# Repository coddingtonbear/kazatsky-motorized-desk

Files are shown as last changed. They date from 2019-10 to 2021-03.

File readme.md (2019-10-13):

header-image

# Kazatsky: DIY Motorized IKEA Desk

The project herein is everything I used for converting my manually-cranked [IKEA Skarsta Desk](https://www.ikea.com/us/en/p/skarsta-desk-sit-stand-white-s49084965/) into a motorized one using parts from a cheap [Harbor Freight 18v Drill Master Drill](https://www.harborfreight.com/18-Volt-38-in-Cordless-DrillDriver-Kit-With-Keyless-Chuck-21-Clutch-Settings-62873.html), a DIY Atmega328pb-based PCB, a [BTS7960 motor driver module](https://www.amazon.com/DEVMO-BTS7960B-Stepper-H-Bridge-Arduino/dp/B07SZ4T699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), a handful of 3D-printed parts, and miscellaneous hardware.

You can also find the 3d-printed parts on Thingiverse: https://www.thingiverse.com/thing:3912988

This is named after the traditional Russian folk dance called the "Kazatsky" because of the parallels that can be drawn between that dance's main movement and the comically fast speed at which this desk can be raised up and down when running the drill at full-bore.

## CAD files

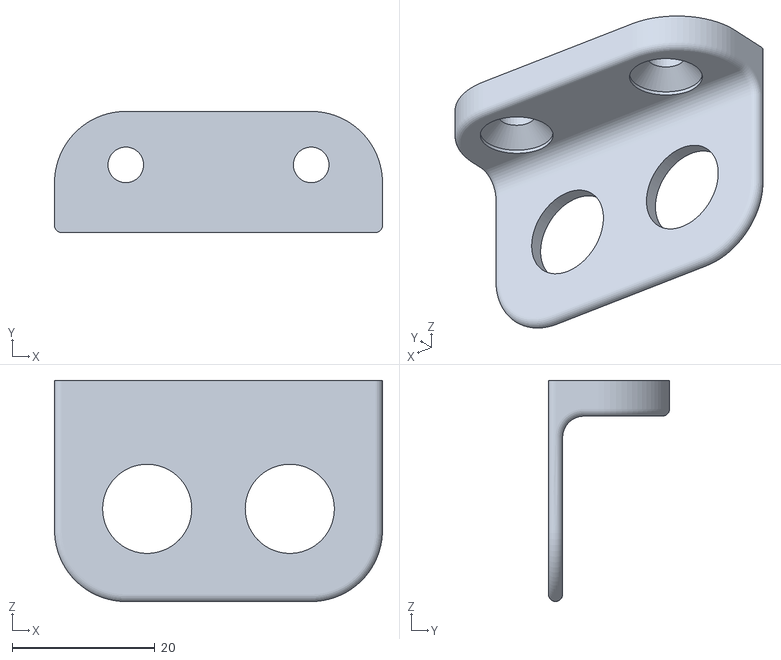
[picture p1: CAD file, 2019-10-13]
3d_parts/Button Panel.stl
46.0 x 17.0 x 31.0

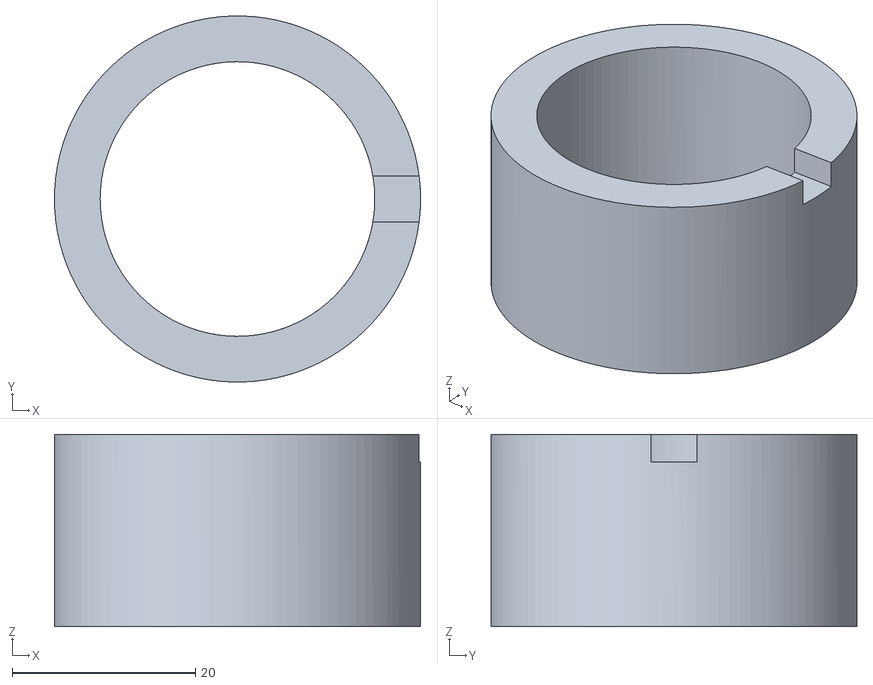
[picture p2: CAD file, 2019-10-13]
3d_parts/DC Motor Chuck Spacer.stl
40.0 x 40.0 x 21.0

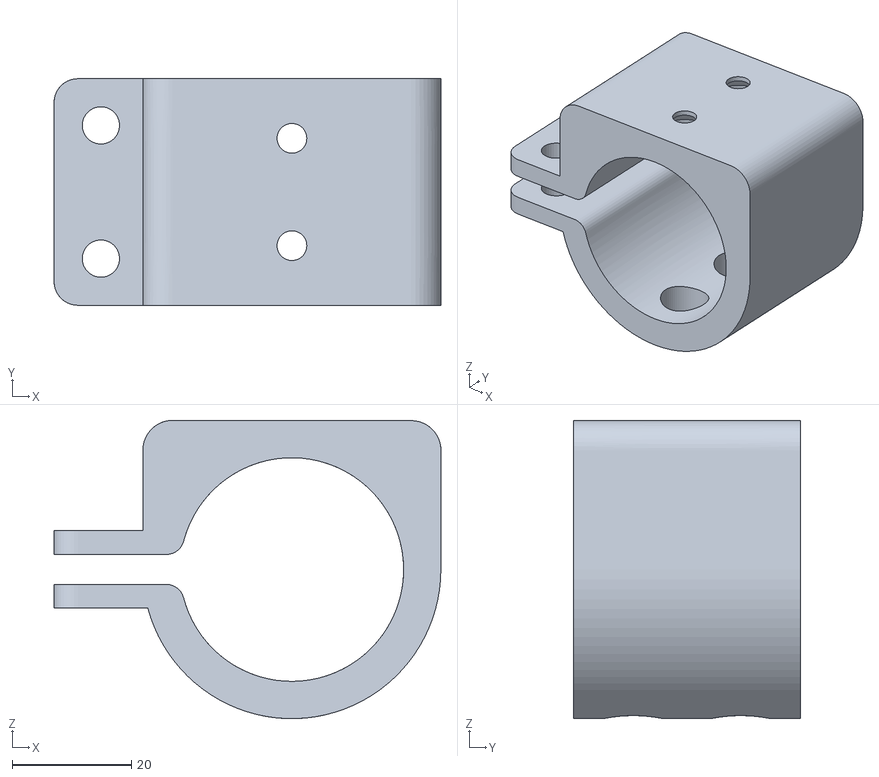
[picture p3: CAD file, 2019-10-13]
3d_parts/DC Motor Mount.stl
64.9 x 38.0 x 50.0

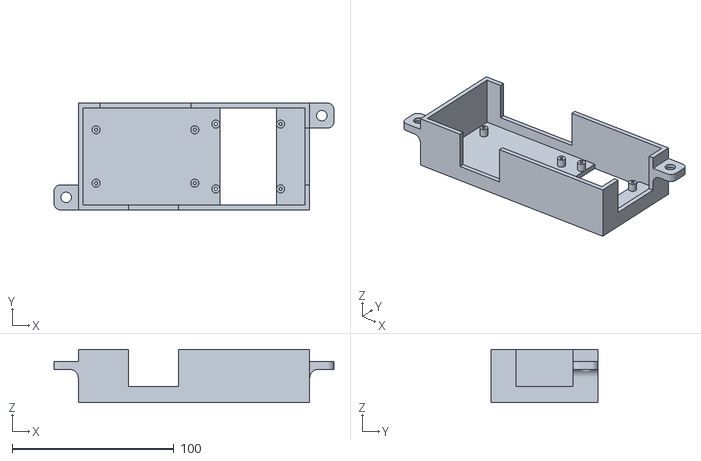
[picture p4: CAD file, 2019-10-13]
3d_parts/PCB Enclosure.stl
173.0 x 66.0 x 33.0

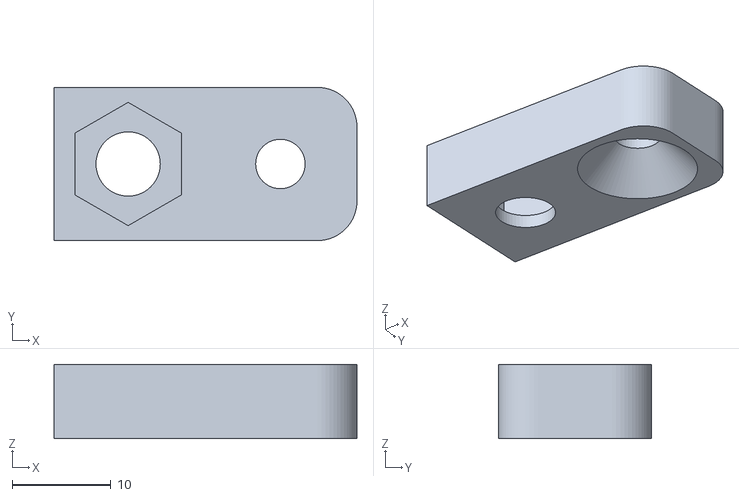
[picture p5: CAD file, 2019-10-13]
3d_parts/PCB Enclosure Mounting Point.stl
30.7 x 15.5 x 7.50

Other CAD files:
3d_parts/Button Panel v3.f3d
3d_parts/DC Motor Chuck Spacer v3.f3d
3d_parts/DC Motor Mount v7.f3d
3d_parts/PCB Box v6.f3d

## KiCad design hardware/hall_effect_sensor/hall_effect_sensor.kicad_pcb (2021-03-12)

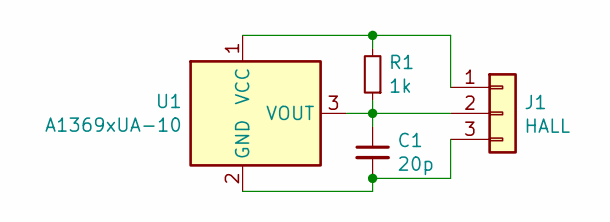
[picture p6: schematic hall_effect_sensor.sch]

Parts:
C1: 20p; 0805_Milling
J1: HALL; PinHeader_1x03_P2.54mm_Vertical
R1: 1k; 0805_Milling
U1: A1369xUA-10; Allegro_SIP-3

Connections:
unnamed: C1.1, J1.2, R1.1, U1.3 (VOUT)
unnamed: C1.2, J1.3, U1.2 (GND)
unnamed: J1.1, R1.2, U1.1 (VCC)

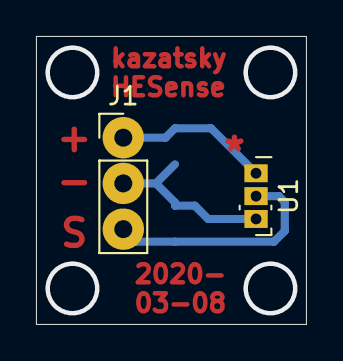
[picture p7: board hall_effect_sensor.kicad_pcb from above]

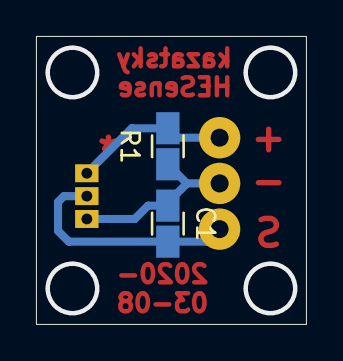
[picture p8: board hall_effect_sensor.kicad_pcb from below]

Board: 2 copper layers, 15.0 x 16.0 mm, 4 parts (2 on the bottom side), 3 nets.

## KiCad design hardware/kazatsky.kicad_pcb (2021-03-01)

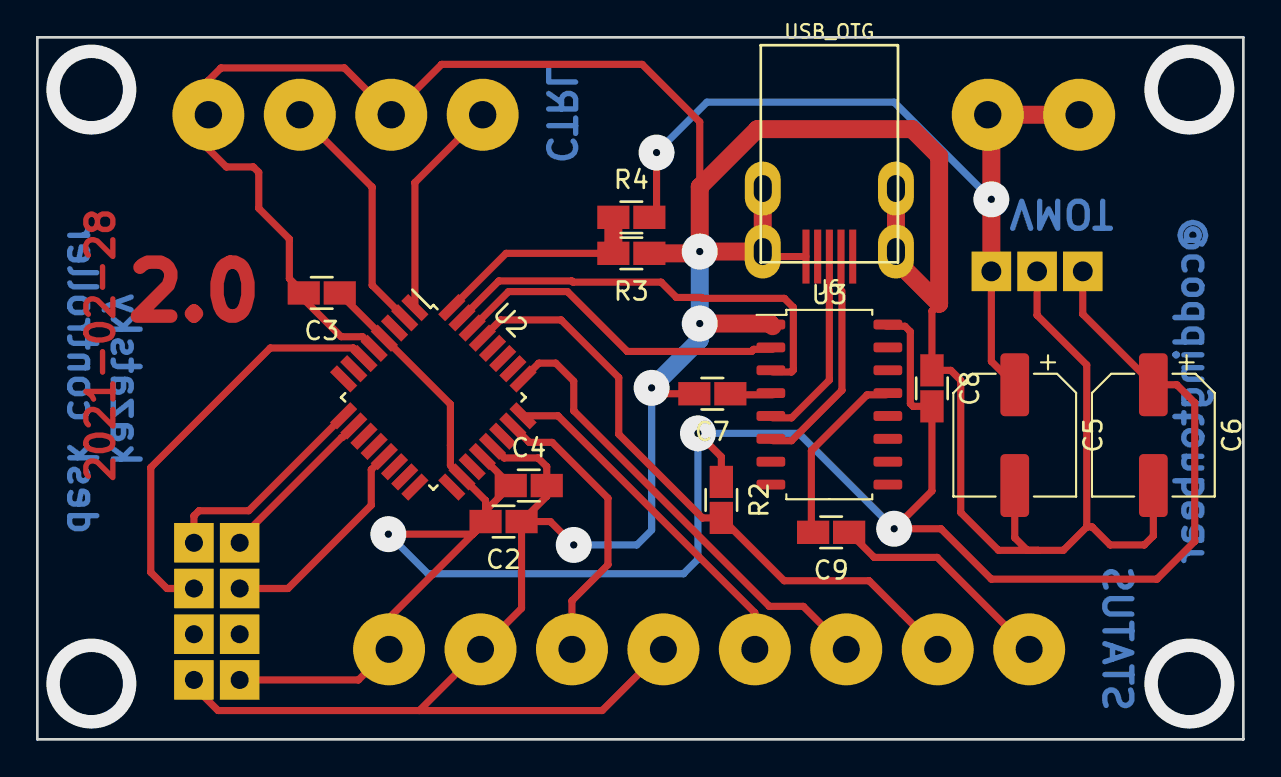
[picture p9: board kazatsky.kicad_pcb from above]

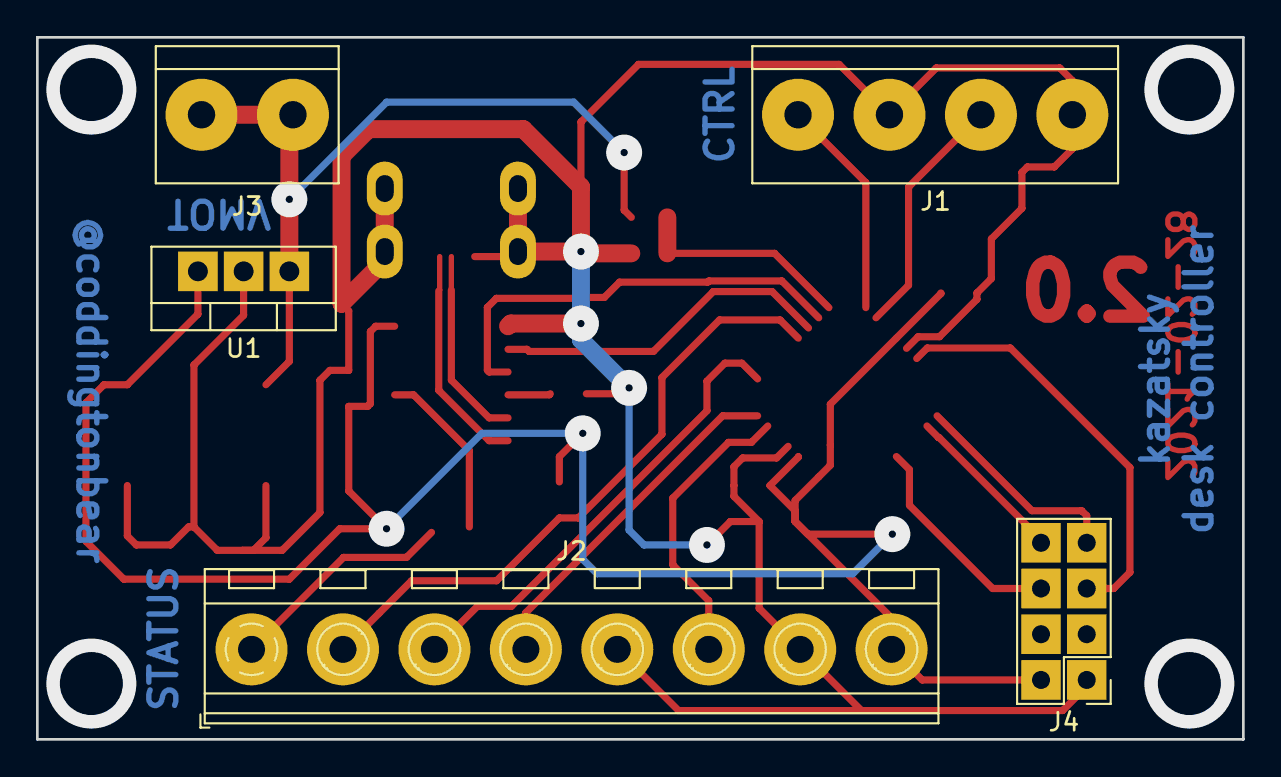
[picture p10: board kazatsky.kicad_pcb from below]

Board: 2 copper layers, 67.0 x 39.0 mm, 19 parts (5 on the bottom side), 21 nets.

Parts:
C2, C3, C4, C7, C8, C9: 0.1u; 0805_Milling
C5, C6: 100u; CP_Elec_6.3x5.4
J1: CTRL; TerminalBlock_bornier-4_P5.08mm
J2: HALL/LIMIT/RST; TerminalBlock_RND_205-00238_1x08_P5.08mm_Horizontal
J3: VMOT; TerminalBlock_bornier-2_P5.08mm
J4: MOTOR; PinHeader_2x04_P2.54mm_Vertical
J6: USB_OTG; UJ2-MIBH-4-SMT
R2: 100k; 0805_Milling
R3: 3.4k; 0805_Milling
R4: 10.2k; 0805_Milling
U1: L7805; TO-220-3_Vertical
U2: ATmega328PB-AU; TQFP-32_7x7mm_P0.8mm
U3: CH340B; SOIC-16_4.55x10.3mm_P1.27mm

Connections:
+5V: C2.2, C3.1, C4.1, C6.1, C8.2, J2.8, J4.2, R2.1, U1.3, U2.4, U2.18, U2.20, U3.16
+VDC: C5.1, J3.1, J3.2, R4.2, U1.1
/UD+: J6.3, U3.5
/UD-: J6.2, U3.6
CTRL_DOWN: J1.2, U2.2
CTRL_UP: J1.4, U2.1
GND: C2.1, C3.2, C4.2, C5.2, C6.2, C7.2, C8.1, J1.1, J1.3, J2.5, J2.7, J4.1, J6.5, J6.6, R3.1, U1.2, U2.5, U2.21, U3.1
HALL: J2.6, U2.23
L_EN: J4.5, U2.6
L_PWM: J4.7, U2.9
unnamed: C7.1, U3.4
unnamed: C9.2, U3.13
unnamed: J2.3, U2.25
RXD: U2.30, U3.2
R_EN: J4.6, U2.13
R_PWM: J4.8, U2.10
TXD: U2.31, U3.3
USB_RESET: J2.2, R2.2, U2.29
USB_RESET_DTR: C9.1, J2.1
VMOT: R3.2, R4.1, U2.32
~LIMIT: J2.4, U2.24

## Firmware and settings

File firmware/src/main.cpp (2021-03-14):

#include <Arduino.h>
#include <BTS7960.h>
#include <Bounce2.h>
#include <EEPROM.h>
#include <SerialCommand.h>

#include "main.h"

#define BASELINE_HEIGHT 72
#define POSITION_TO_MM 0.45
#define POSITION_MAX 95

#define BUTTON_UP 3
#define BUTTON_DOWN 4
#define BUTTON_DEBOUNCE_MS 25

#define MOT_L_EN 23
#define MOT_L_PWM 5
#define MOT_R_EN 9
#define MOT_R_PWM 6

//#define MOT_PWR_VOLTAGE A5
#define MOT_HALL 14
#define MOT_HALL_DEBOUNCE_MS 10

#define LIMIT_MIN 15

#define EEPROM_STORE_MAGIC 24
#define EEPROM_STORE_SIGNAL 99
#define EEPROM_POSITION 100

BTS7960 motor(MOT_R_PWM, MOT_L_PWM, MOT_L_EN, MOT_R_EN);

#define SPEED_SETTLE_RAMP 500
#define SPEED_RAMP 1000
#define SPEED 175

#define TICK_ON 100
#define TICK_INTERVAL 25
#define TICK_SPEED 1

SerialCommand cmd;

int lastHallState = HIGH;
bool up = true;
uint8_t position = 0;
uint8_t lastPosition = 0;

bool motorDisabled = false;
unsigned long stoppingStarted = 0;
unsigned long movementStarted = 0;
bool isMoving = false;
bool wasMoving = false;
bool buttonsLocked = false;

unsigned long lastButtonCheck = 0;

Bounce buttonUp = Bounce();
Bounce buttonDown = Bounce();
Bounce hall = Bounce();

void handleMotorPosition()
{
    int limitTripped = digitalRead(LIMIT_MIN);

    if (limitTripped == LOW && !up && isMoving) {
        resetPosition();
        motorStop();
        buttonLockout();
        tick(5);
    } else {
        buttonLockout(false);
    }

    int currentHallState = hall.read();
    if(currentHallState == HIGH) {
        Serial.print("H");
    }
    lastPosition = position;

    if (lastHallState == HIGH && currentHallState == LOW) {
        if (up) {
            position++;
        } else {
            position--;
        }
        lastHallState = currentHallState;
    }
    lastHallState = currentHallState;
}

bool positionHasChanged()
{
    return lastPosition != position;
}

void cmdUnrecognized(const char*)
{
    Serial.println("Unrecognized command");
}

void cmdGetPosition()
{
    Serial.println(getPosition());
}

void cmdGetHeight()
{
    Serial.println(getHeight());
}

void cmdToPosition()
{
    int target;

    char* targetStr = cmd.next();
    if (targetStr) {
        target = atoi(targetStr);
        toPosition(target);
    }
}

void tick(uint8_t count)
{
    motor.setSpeed(TICK_SPEED);


    for(uint8_t i = 0; i<count; i++) {
        motor.enable();
        delay(TICK_ON);
        motor.disable();
        delay(TICK_INTERVAL);
    }
}

void cmdToHeight()
{
    int target;

    char* targetStr = cmd.next();
    if (targetStr) {
        target = atoi(targetStr);
        toHeight(target);
    }
}

void resetPosition()
{
    position = 0;
    storePosition();
}

void cmdResetPosition()
{
    resetPosition();
}

void toPosition(int target)
{
    unsigned long timeout = millis() + 10000;

    if (target < 0 || target > POSITION_MAX) {
        return;
    }

    while (position != target && millis() < timeout) {
        if (position > target) {
            motorDown();
        } else {
            motorUp();
        }

        _loop();
    }
}

float getHeight()
{
    return BASELINE_HEIGHT + (POSITION_TO_MM * getPosition());
}

int getPosition()
{
    return position;
}

void toHeight(float mm)
{
    int targetPosition = (mm - BASELINE_HEIGHT) / POSITION_TO_MM;
    toPosition(targetPosition);
}

void storePosition()
{
    EEPROM.update(EEPROM_STORE_SIGNAL, EEPROM_STORE_MAGIC);
    EEPROM.update(EEPROM_POSITION, position);
}

void setup()
{
    pinMode(LIMIT_MIN, INPUT_PULLUP);

    buttonUp.attach(BUTTON_UP, INPUT_PULLUP);
    buttonDown.attach(BUTTON_DOWN, INPUT_PULLUP);
    hall.attach(MOT_HALL, INPUT);

    cmd.addCommand("to_height", cmdToHeight);
    cmd.addCommand("get_height", cmdGetHeight);
    cmd.addCommand("to_position", cmdToPosition);
    cmd.addCommand("get_position", cmdGetPosition);
    cmd.addCommand("reset_position", cmdResetPosition);
    cmd.setDefaultHandler(cmdUnrecognized);

    motor.stop();
    motor.disable();

    Serial.begin(9600);

    Serial.println("<Ready>");

    if (EEPROM.read(EEPROM_STORE_SIGNAL) == EEPROM_STORE_MAGIC) {
        position = EEPROM.read(EEPROM_POSITION);
    } else {
        position = 0;
    }

    // Safety machinery
    if (digitalRead(BUTTON_UP) == LOW && digitalRead(BUTTON_DOWN) == LOW) {
        motorDisabled = true;
        tick(10);
    } else {
        tick(3);
    }
}

uint8_t getRampedSpeed() {
    return float(SPEED) * min(1, float(millis() - movementStarted) / float(SPEED_RAMP));
}

uint8_t getRampedSettlingSpeed() {
    return float(getRampedSpeed()) * (1 - min(1, float(millis() - stoppingStarted) / float(SPEED_SETTLE_RAMP)));
}

void motorUp()
{
    if(motorDisabled) {
        return;
    }
    if (movementStarted == 0) {
        movementStarted = millis();
    }

    motor.enable();
    motor.setSpeed(getRampedSpeed());
    isMoving = true;
    up = true;
}

void motorDown()
{
    if(motorDisabled) {
        return;
    }
    if (movementStarted == 0) {
        movementStarted = millis();
    }

    motor.enable();
    motor.setSpeed(-1 * getRampedSpeed());
    isMoving = true;
    up = false;
}

void motorSettle() {
    if(motorDisabled || !isMoving) {
        motorStop();
        return;
    }
    if (stoppingStarted == 0) {
        stoppingStarted = millis();
    }

    int speed = getRampedSettlingSpeed() * (up ? 1 : -1);
    if (speed == 0) {
        stoppingStarted = 0;
        motorStop();
    } else {
        motor.enable();
        motor.setSpeed(speed);
    }
}

void motorStop()
{
    movementStarted = 0;
    isMoving = false;
    motor.stop();
}

void buttonLockout(bool locked)
{
    buttonsLocked = locked;
}

void _loop()
{
    buttonUp.update();
    buttonDown.update();
    hall.update();

    if (millis() - lastButtonCheck > 100) {

        int buttonUpState = buttonUp.read();
        int buttonDownState = buttonDown.read();

        wasMoving = isMoving;
        lastButtonCheck = millis();
        if (buttonUpState == LOW && buttonDownState == LOW) {
            motorStop();
            resetPosition();
        } else if (positionHasChanged() && getPosition() == 0) {
            buttonLockout();
            motorStop();
        } else if (buttonUpState == LOW) {
            motorUp();
        } else if (!buttonsLocked && buttonDownState == LOW) {
            motorDown();
        } else {
            motorSettle();
        }
        if(isMoving) {
            if(stoppingStarted) {
                Serial.print("<Stopping: speed=");
            } else {
                Serial.print("<Moving: speed=");
            }
            Serial.print(stoppingStarted ? getRampedSettlingSpeed() : getRampedSpeed());
            Serial.print(" position=");
            Serial.print(getPosition());
            Serial.print(" height=");
            Serial.print(getHeight());
            Serial.print(" direction=");
            Serial.print(up ? "up" : "down");
            Serial.println(">");
        }
        if (wasMoving && !isMoving) {
            storePosition();
        }
    }

    handleMotorPosition();
}

void loop()
{
    cmd.readSerial();

    _loop();
}

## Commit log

2019-10-08 Addinv v1 of the board design.
    [kazatsky.kicad_pcb, kazatsky.sch]
2019-10-08 Adding ADC pin for measuring input voltage.
    [kazatsky.kicad_pcb, kazatsky.sch]
2019-10-08 Adding name/date/etc to board.
    [kazatsky.kicad_pcb]
2019-10-08 Minor gnd/5v layout changes.
    [kazatsky.kicad_pcb]
2019-10-08 Adding gerbers and gcode.
    [kazatsky-Alignment.gbr, kazatsky-B.Cu.gbr, kazatsky-Edge.Cuts.gbr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]
2019-10-11 Latest hardware version.
    [kazatsky-B.Cu.gbr, kazatsky-Edge.Cuts.gbr, kazatsky-F.Cu.gbr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]
2019-10-12 Fully-working; including keeping track of position between resets & reading from hall effect sensor.
    [main.cpp]
2019-10-13 Add commands for resetting desk zero point, and getting current input voltage.
    [main.cpp]
2019-10-13 Adding 3d-printable parts.
    [Button Panel v3.f3d, Button Panel.stl, DC Motor Chuck Spacer v3.f3d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]
2020-07-05 Debounce hall effect sensor & button inputs; detect motor stall.
    [main.cpp]
2021-03-01 Updating to v2.0 of the board.
    [kazatsky.kicad_pcb, kazatsky.sch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]
2021-03-01 Adding extra capacitance.
    [kazatsky.kicad_pcb, kazatsky.sch]
2021-03-01 Updating board version/date.
    [kazatsky.kicad_pcb]
2021-03-06 PCB v2.0.
2021-03-06 Use the motor to make a beeping noise at start, limit.
    [main.cpp]
2021-03-09 Adding offboard hall effect sensor.
    [hall_effect_sensor.kicad_pcb, hall_effect_sensor.sch]
2021-03-09 Updating board to include mounting holes.
    [hall_effect_sensor.kicad_pcb]
2021-03-09 Updating footprint for hall-effect sensor.
    [hall_effect_sensor.kicad_pcb]
2021-03-12 Updating hall effect board slightly.
    [hall_effect_sensor.kicad_pcb]
2021-03-14 Slowly ramp speed up/down when pressing/releasing buttons. Display current status on output. Add motor safety functionality for disabling motors in the event of a firmware problem.
    [main.cpp]
2021-03-14 Removing motor stall detection; just rely on the limit switch, it's fine.
    [main.cpp]
